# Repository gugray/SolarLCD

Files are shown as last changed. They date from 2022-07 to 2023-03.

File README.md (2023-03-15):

# LCD Solar Creatures

This repository has all the code and design files for the low-power LCD Solar Creatures
[documented on Hackaday](https://hackaday.io/project/185825-lcd-solar-creatures).

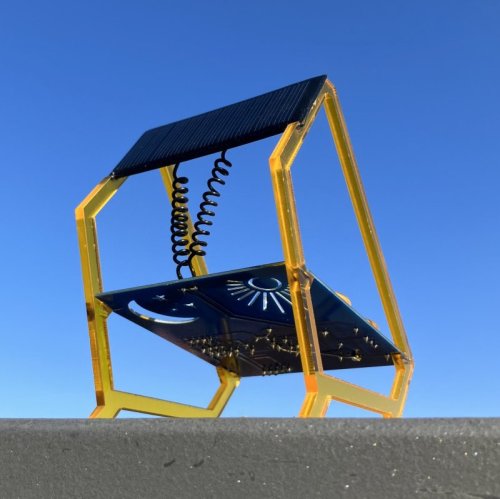
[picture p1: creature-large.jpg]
Window Squatter, the larger solar creature

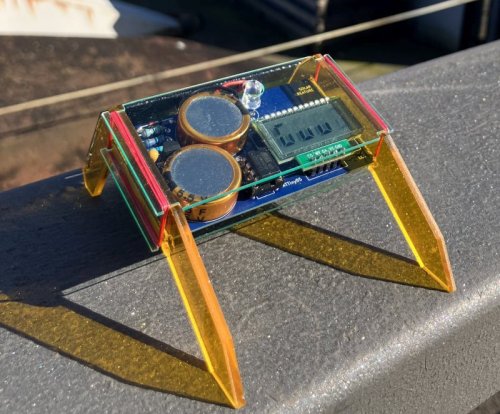
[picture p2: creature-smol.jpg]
Desktop Crawler, the smaller solar creature


The Solar Creatures are based on a simple 7-segment LCD display and an ATtiny85 microcontroller. They store their energy in a pair of 1.5F supercapacitors that can power them through the night.

When the sun shines, the display plays lively animations: a tiny version of Conway's Game of Life, or randomized rhythmic patterns. As the light fades, the animations slow down, and at night the creatures use their high-power red LED instead to beam out a rhythm. The Creatures draw 11.4μA, 7.3μA and 6.2μA in these modes, respectively.

The Solar Creatures are infused with patterns through and through. The animations and the flashes are all randomly parameterized Euclidean rhythms. You will rarely see the same show twice!

They recognize the periodic peaks and lows of energy, and they keep track of their own age in days. They faithfully report this to you in between two animations, and they also tell you how long they were awake in the last few days.

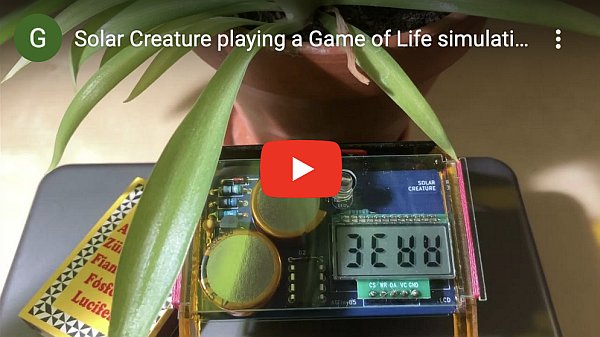
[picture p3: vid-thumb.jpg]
Watch the Game of Life animation (https://youtu.be/l91HPv1WXeA)


## Electronics

I designed the schematic and PCB of the creatures in KiCad 5.1.9. The circuitry of the two forms is identical, but because the PCB is different, there are two separate projects. You can find them under [/electronics/v6](electronics/v6) (for larger the Window Squatter) and under [/electronics/vB1](electronics/vB1) (for the smaller Desktop Crawler). The ZIP files with gerber in their name are the exports that I submitted to the PCB fab.

## Laser-cut frame

The frame of both creatures is laser-cut from 3mm acryclic. The vector files for this are in [/design](design). The .ai files are the originals, but I included a version re-saved as Inkscape .svg as well.

## Source code

The source code is straightforward C++ with no bells or whistles. You can find it in [/code/board](code/board). I developed in using the [PlatformIO extension](https://platformio.org/install/ide?install=vscode) for Visual Studio Code, so if you want to explore the code and build it yourself, that might be the easiest way to get started.

The code uses the Arduino framework, but beyond that it has no dependencies and includes no libraries. That's partly because there are no peripherals apart from the  LCD display's HT1621 chip, and partly because any cruft had to be trimmed off to fit into the ATtiny's 8KB flash memory. The HT1621 driver is based on existing precursors (credited at the top of the source files), but it had to be largely reworked to match the weird display I got from AliExpress.

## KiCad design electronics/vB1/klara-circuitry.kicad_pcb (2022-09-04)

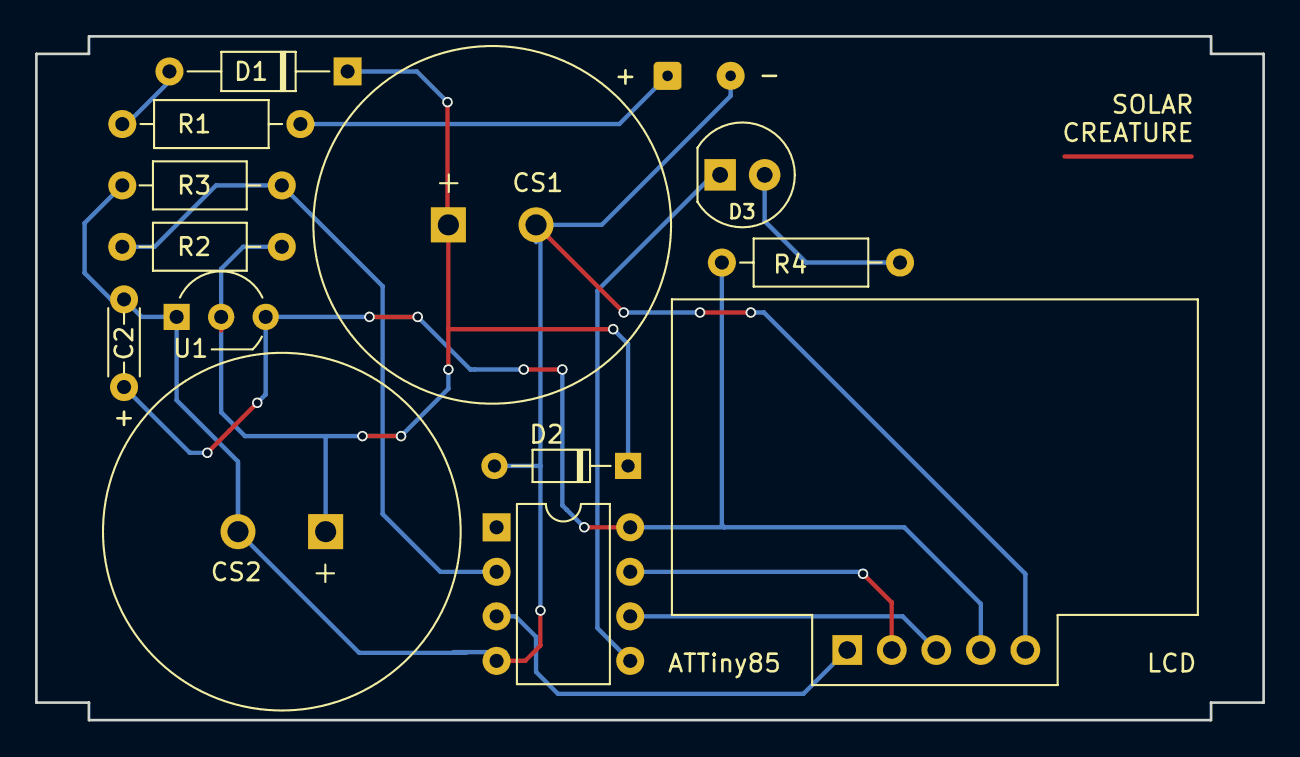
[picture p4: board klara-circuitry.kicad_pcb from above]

Board: 2 copper layers, 70.0 x 39.0 mm, 14 parts (0 on the bottom side), 11 nets.

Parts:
C2: 1uF; C_Rect_L7.0mm_W2.0mm_P5.00mm
CS1, CS2: 1.5F; CP_Radial_D20.0mm_P5.00mm
D1: 1N60; D_DO-35_SOD27_P10.16mm_Horizontal
D2: Zener; D_DO-34_SOD68_P7.62mm_Horizontal
D3: LED; LED_D5.0mm
LCD: HT1621; LCD_SPI
R1: 59; R_Axial_DIN0207_L6.3mm_D2.5mm_P10.16mm_Horizontal
R2: 1M; R_Axial_DIN0207_L6.3mm_D2.5mm_P10.16mm_Horizontal
R3: 100k; R_Axial_DIN0207_L6.3mm_D2.5mm_P10.16mm_Horizontal
R4: 330; R_Axial_DIN0207_L6.3mm_D2.5mm_P10.16mm_Horizontal
SC1: Solar_Cell; SolderWire-0.1sqmm_1x02_P3.6mm_D0.4mm_OD1mm
U1: MCP1700-3302E; TO-92_Inline_Wide
U3: ATtiny85; DIP-8_W7.62mm

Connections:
unnamed: C2.1, LCD.4, R4.1, U1.3, U3.8
unnamed: C2.2, CS1.2, CS2.2, D2.2, LCD.5, R3.2, SC1.2, U1.1, U3.4
unnamed: CS1.1, CS2.1, D1.1, D2.1, R2.1, U1.2
unnamed: D1.2, R1.2
unnamed: D3.1, U3.5
unnamed: D3.2, R4.2
unnamed: LCD.1, U3.3
unnamed: LCD.2, U3.7
unnamed: LCD.3, U3.6
unnamed: R1.1, SC1.1
unnamed: R2.2, R3.1, U3.2

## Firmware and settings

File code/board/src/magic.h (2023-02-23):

#ifndef MAGIC_H
#define MAGIC_H

#define VCC_HALF_HYSTERESIS   3
#define MID_VCC_THRESHOLD     328
#define HIGH_VCC_THRESHOLD    410

// It's a new day if creature rises into mid-voltage after at least
// this number of minutes in low.
#define NEWDAY_MIN_MINUTES_IN_LOW  240

// To be empirically determined for every unit.
// First large unit: 23/20
// First small unit: 1/1
#define TIME_CORR_NUMERATOR   1
#define TIME_CORR_DENOMINATOR 1

#ifdef ENV_ATTINY
#define PIN_CS    4
#define PIN_WR    2
#define PIN_DATA  1
#define PIN_LED   0
#endif

#ifdef ENV_NANO
#define PIN_CS    11
#define PIN_WR    12
#define PIN_DATA  7
#define PIN_LED   13
#endif

#endif

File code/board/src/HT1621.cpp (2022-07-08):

/*******************************************************************************
MIT license
Copyright 2016-2018 anxzhu (github.com/anxzhu)
https://github.com/anxzhu/segment-lcd-with-ht1621
Copyright 2018-2020 Valerio Nappi (github.com/valerionew) (changes)
https://github.com/valerionew/ht1621-7-seg
Copyright 2022 Gabor L Ugray (changes; reduced scope)
*******************************************************************************/

#include <Arduino.h>
#include "HT1621.h"
#include "magic.h"

#define BIAS 0b01010010    // 1/3 duty 4 commons
#define SYSDIS 0b00000000  // 关振系统荡器和LCD偏压发生器 ~ disable sys oscillator and LCD bias
#define SYSEN 0b00000010   // 打开系统振荡器 ~ enable system oscillator
#define LCDOFF 0b00000100  // 关LCD偏压 ~ disable LCD bias generator
#define LCDON 0b00000110   // 打开LCD偏压 ~ enable LCD bias generator
#define XTAL 0b00101000    // 外部接时钟 ~ external quartz crystal
#define RC256 0b00110000   // 内部时钟 ~ internal RC oscillator
#define WDTDIS1 0b00001010 // 禁止看门狗 ~ disable watchdog timer

HT1621::HT1621()
{
  enabled = false;
  clearBuffer();
}

bool HT1621::isEnabled()
{
  return enabled;
}

void HT1621::clearBuffer()
{
  memset(&buffer[0], 0, HT1621_BUFSZ);
}

void HT1621::begin()
{
  // Using them as output
  pinMode(PIN_CS, OUTPUT);
  pinMode(PIN_WR, OUTPUT);
  pinMode(PIN_DATA, OUTPUT);
  // Init sequence
  wrCmd(BIAS);
  wrCmd(RC256);
  wrCmd(SYSDIS);
  wrCmd(WDTDIS1);
  wrCmd(SYSEN);
  wrCmd(LCDON);
  // Clear sequence
  uint8_t i, addr;
  for (i = 0, addr = 0; i < 16; i++)
  {
    digitalWrite(PIN_CS, LOW);
    wrData(0xa0, 3);
    wrData((addr << 2), 6);
    wrData(0, 8);
    digitalWrite(PIN_CS, HIGH);
    addr = addr + 2;
  }
  enabled = true;
}

void HT1621::wrData(uint8_t data, uint8_t cnt)
{
  uint8_t i;
  for (i = 0; i < cnt; i++)
  {
    digitalWrite(PIN_WR, LOW);
    delayMicroseconds(4);
    digitalWrite(PIN_DATA, (data & 0x80) ? HIGH : LOW);
    digitalWrite(PIN_WR, HIGH);
    delayMicroseconds(4);
    data <<= 1;
  }
}

void HT1621::setEnabled(bool enabled)
{
  if (this->enabled == enabled)
    return;
  this->enabled = enabled;

  if (enabled)
  {
    wrCmd(SYSEN); // System oscillator
    wrCmd(LCDON); // LCD bias generator
  }
  else
  {
    // This turns off both system oscillator and LCD bias generator
    wrCmd(SYSDIS);
  }
}

void HT1621::wrCmd(uint8_t cmd)
{
  digitalWrite(PIN_CS, LOW);
  wrData(0x80, 4);
  wrData(cmd, 8);
  digitalWrite(PIN_CS, HIGH);
}

// takes the buffer and puts it straight into the driver
void HT1621::wrBuffer()
{
  for (uint8_t ix = 0; ix < 4; ++ix)
  {
    // Write one buffer position
    uint8_t segData = buffer[ix];
    uint8_t addr = 3 - ix;
    addr <<= 3;
    digitalWrite(PIN_CS, LOW);
    wrData(0xa0, 3);
    wrData(addr, 6);
    wrData(segData, 8);
    digitalWrite(PIN_CS, HIGH);
  }
}

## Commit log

2022-06-06 voltage observer logic WIP
2022-06-15 voltage-dependent behavior experimentation
2022-06-18 working on power saving
2022-06-19 fix: low-voltage (blinker) mode didn't turn off LCD
2022-06-19 schematic and design (WIP)
    [klara-circuitry.kicad_pcb, klara-circuitry.sch]
2022-06-19 evolution of schematic v1-v2-v3
    [klara-circuitry.kicad_pcb, klara-circuitry.sch]
2022-06-29 code for external voltage observer via nano
2022-07-03 new LED wiring; animation fixes
2022-07-03 temperature measured & shown
2022-07-04 temp measurement in voltage board
2022-07-05 design & schematic wip
    [klara-circuitry.sch]
2022-07-05 final (?) schematic
    [klara-circuitry.kicad_pcb, klara-circuitry.sch]
2022-07-08 current day and past day uptimes
2022-07-09 fixes: current day and past day uptimes
2022-07-09 removed temperature
2022-07-16 PCB WIP
    [klara-circuitry.kicad_pcb, klara-circuitry.sch]
2022-07-17 fix: history had uncalibrated (lower) awake time
    [magic.h]
2022-07-17 for the record: earlier board voltage measurement data
    [v-01.xlsx]
2022-07-17 design/pcb finalized for manufacturing
    [klara-circuitry-B_Cu.gbr, klara-circuitry-B_Mask.gbr, klara-circuitry-B_SilkS.gbr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]
2022-07-29 fix: detecting new day if MCU doesn't power off in a short night
    [magic.h]
2022-08-13 fixes to penta frame pcb; alternative small pcb
    [klara-circuitry.kicad_pcb, klara-circuitry.sch]
2022-08-31 PCB update
    [klara-circuitry-B_Cu.gbr, klara-circuitry-B_Mask.gbr, klara-circuitry-B_SilkS.gbr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]
2022-08-31 rhythmic LED blinkie
2022-09-04 tweak: blink unless voltage clearly growing
2022-09-04 circuit d'oh: measure supercap voltage, not regulator output
    [klara-circuitry.kicad_pcb, klara-circuitry.sch]
2023-02-23 time correction for small creature (none needed)
    [magic.h]
2023-02-23 fix (maybe): no blinking on some nights
    [blink_seq.cpp]
2023-03-14 added Inkscape SVG conversion of frame design files
2023-03-14 remove superceded electroncs and design versions
    [klara-circuitry.kicad_pcb, klara-circuitry.sch]
2023-03-14 remove superceded code experiments
    [v-01.xlsx]
2023-03-15 rename gerber files; video thumbnal
